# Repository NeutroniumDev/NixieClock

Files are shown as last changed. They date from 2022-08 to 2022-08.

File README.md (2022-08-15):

# NixieClock
  NOTE: this is not a completed project. The code is incomplete, and therefor the hardware has not been fully tested. DON'T BUILD THIS YET, OR ASSUME RISKS. 

  A clock consisting of 6 nixie tubes, controlled by 3 high voltage shift registers. It differs from most other nixie clocks in that every segment of every nixie tube can be turned on, as opposed to one number per tube. This enables more complex animations. The 3 high voltage shift registers also, theoretically (not implemented) support controlling more than 6 nixie tubes because of leftover pins. The clock uses an ESP32-C3 to enable synchronizing the time with NTP, and it also acts as the microcontroller. Finally, the clock technically has an RTC chip, although in retrospect it's sorta unnecessary (and not implemented in code lmao).

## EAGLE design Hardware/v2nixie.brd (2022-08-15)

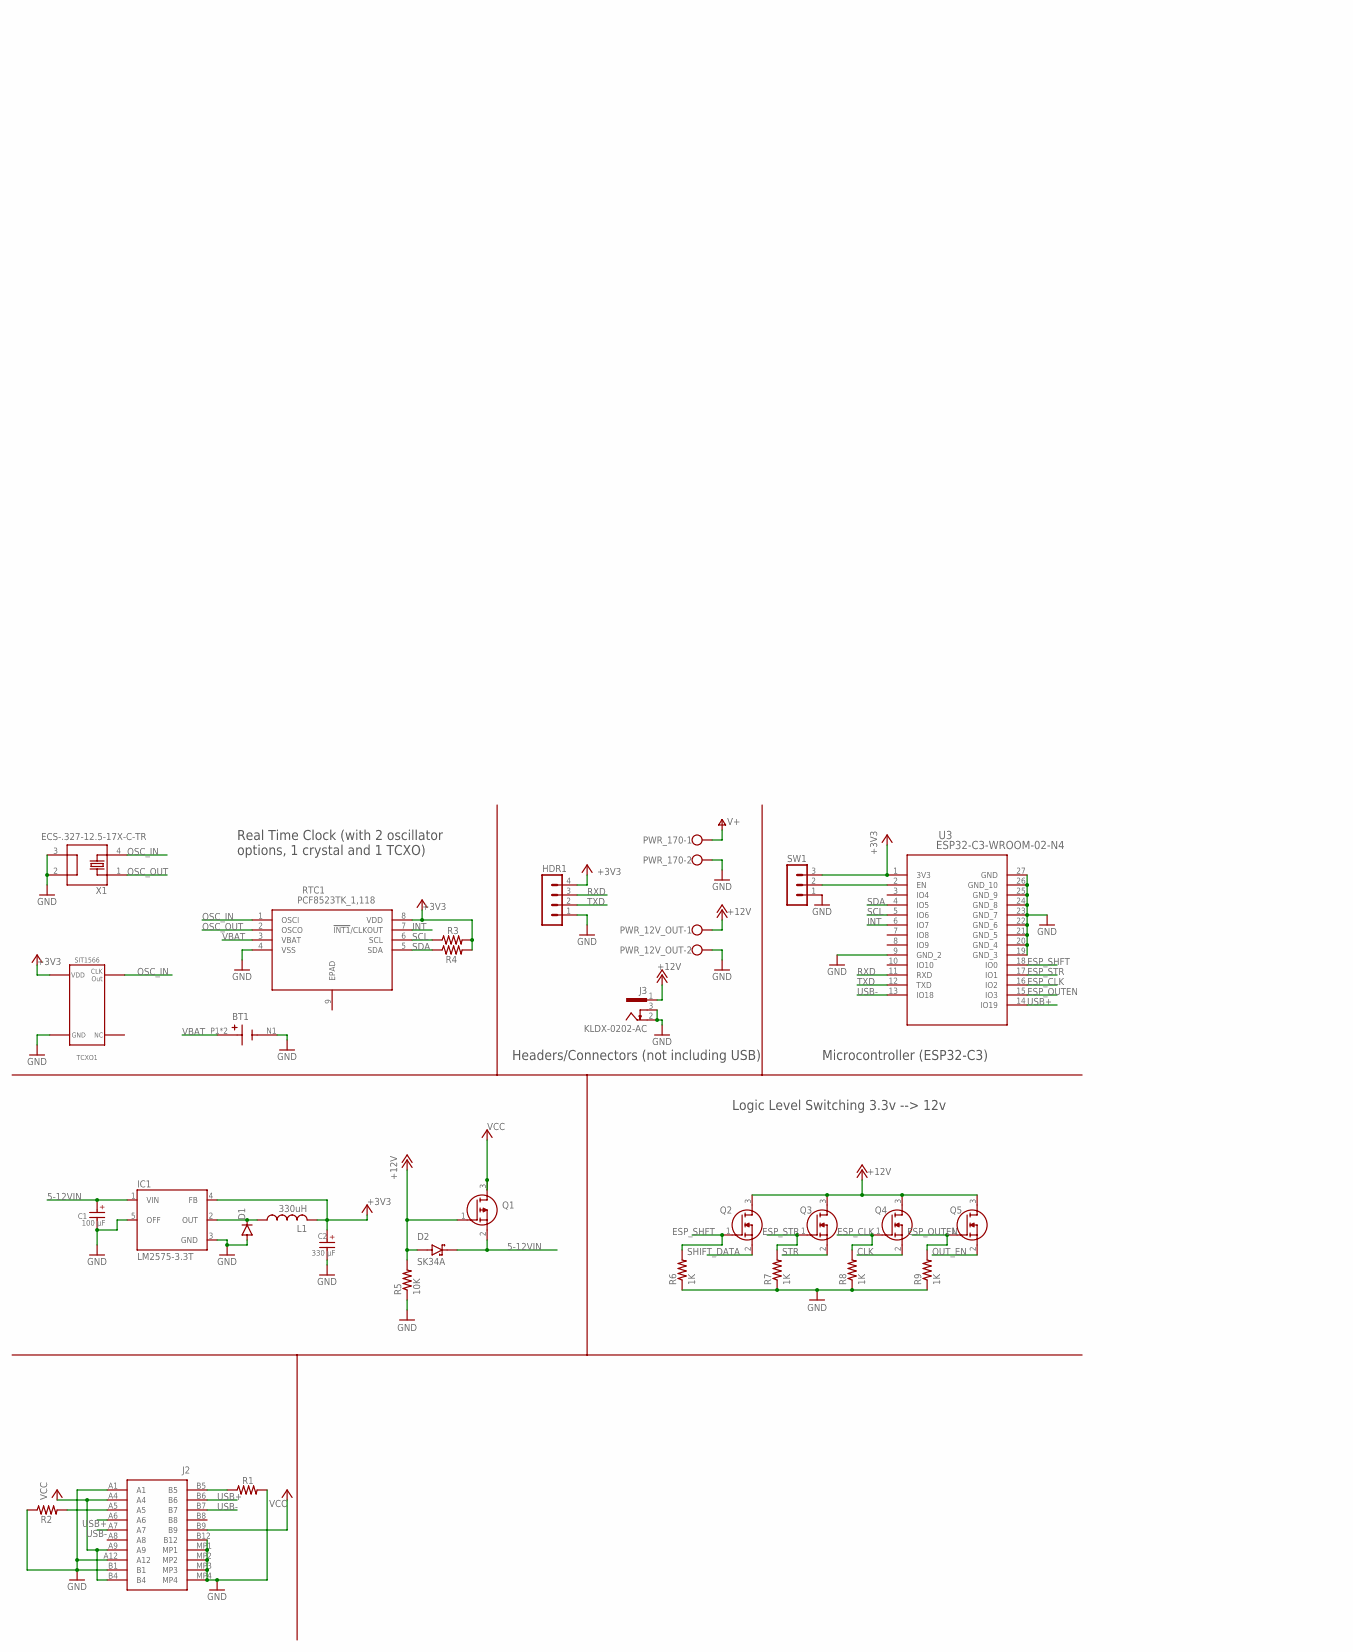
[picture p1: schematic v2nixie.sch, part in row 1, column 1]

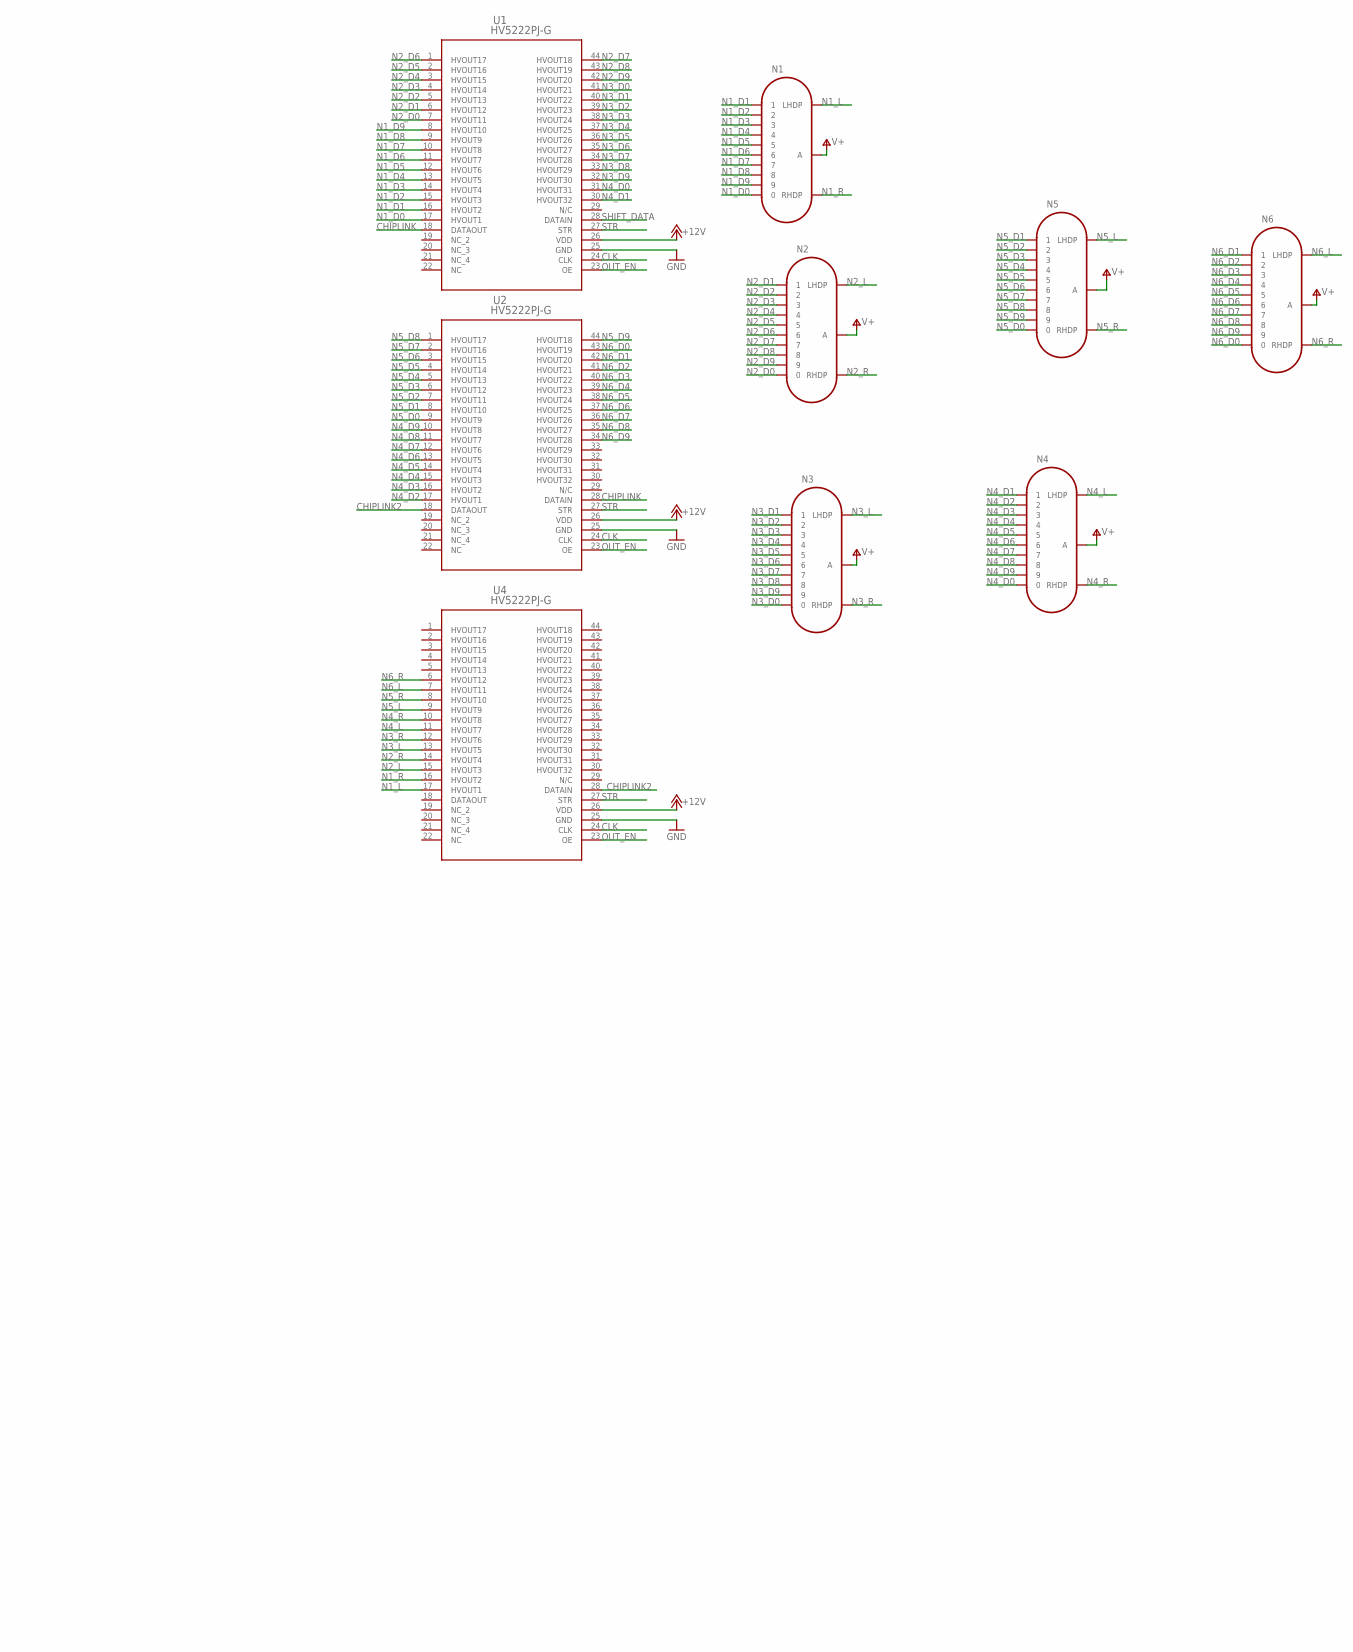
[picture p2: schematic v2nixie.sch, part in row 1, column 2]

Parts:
BT1: BAT-HLD-001-TR; BAT_BAT-HLD-001-TR
C1: 100 µF; WCAP-PTG5_8X11.5(DXL)
C2: 330 µF; WCAP-PTG5_8X8(DXL)
D1: DIODE-DO201-15; DO201-15
D2: SK34A; DIOM4325X250N
HDR1: MA04-1
IC1: LM2575-3.3T; TO220-5
J2: USB4110-GF-A; USB4110GFA
J3: KLDX-0202-AC; KYCON_KLDX-0202-AC
L1: 330uH; 6000-XXXX-RC
N1, N2, N3, N4, N5, N6: IN-14
PWR_12V_OUT, PWR_170: W237-102
Q1: SSM3J117TU,LF_T; SSM3J117TULFT
Q2, Q3, Q4, Q5: RU1J002YNTCL; SOTFL65P210X105-3N
R1, R2: 5.1K; R0805
R3, R4: 10K; R0805
R5: 10K; M0805
R6, R7, R8, R9: 1K; M0805
RTC1: PCF8523TK_1,118; SON80P400X400X100-9N
SW1: MA03-1
TCXO1: SIT1566
U1, U2, U4: HV5222PJ-G; PLCC44_MC_MCH
U3: ESP32-C3-WROOM-02-N4; IC18_ESP32-C3-WROOM-02-N4_EXP
X1: ECS-.327-12.5-17X-C-TR; XTAL_ECS-.327-12.5-17X-C-TR

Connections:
5-12VIN: C1.1 (+), D2.C (K), IC1.1 (VIN), Q1.2 (S)
+3V3: C2.1 (+), HDR1.4, IC1.4 (FB), L1.2, R3.2, R4.2, RTC1.8 (VDD), SW1.3, TCXO1.VDD, U3.1 (3V3)
+12V: D2.A, J3.1, PWR_12V_OUT.1, Q1.1 (G), Q2.3 (D), Q3.3 (D), Q4.3 (D), Q5.3 (D), R5.2, U1.26 (VDD), U2.26 (VDD), U4.26 (VDD)
CHIPLINK: U1.18 (DATAOUT), U2.28 (DATAIN)
CHIPLINK2: U2.18 (DATAOUT), U4.28 (DATAIN)
CLK: Q4.2 (S), U1.24 (CLK), U2.24 (CLK), U4.24 (CLK)
ESP_CLK: Q4.1 (G), R8.2, U3.16 (IO2)
ESP_OUTEN: Q5.1 (G), R9.2, U3.15 (IO3)
ESP_SHFT: Q2.1 (G), R6.2, U3.18 (IO0)
ESP_STR: Q3.1 (G), R7.2, U3.17 (IO1)
GND: BT1.N1 (-), C1.2 (-), C2.2 (-), D1.A, HDR1.1, IC1.3 (GND), IC1.5 (OFF), J2.A1, J2.A12, J2.B1, J2.B12, J2.MP1, J2.MP2, J2.MP3, J2.MP4, J3.2, J3.3, PWR_12V_OUT.2, PWR_170.2, R1.2, R2.1, R5.1, R6.1, R7.1, R8.1, R9.1, RTC1.4 (VSS), SW1.1, TCXO1.GND, U1.25 (GND), U2.25 (GND), U3.9 (GND_2), U3.19 (GND_3), U3.20 (GND_4), U3.21 (GND_5), U3.22 (GND_6), U3.23 (GND_7), U3.24 (GND_8), U3.25 (GND_9), U3.26 (GND_10), U3.27 (GND), U4.25 (GND), X1.2, X1.3
INT: RTC1.7 (!INT1!/CLKOUT), U3.6 (IO7)
N1_D0: N1.0, U1.17 (HVOUT1)
N1_D1: N1.1, U1.16 (HVOUT2)
N1_D2: N1.2, U1.15 (HVOUT3)
N1_D3: N1.3, U1.14 (HVOUT4)
N1_D4: N1.4, U1.13 (HVOUT5)
N1_D5: N1.5, U1.12 (HVOUT6)
N1_D6: N1.6, U1.11 (HVOUT7)
N1_D7: N1.7, U1.10 (HVOUT8)
N1_D8: N1.8, U1.9 (HVOUT9)
N1_D9: N1.9, U1.8 (HVOUT10)
N1_L: N1.LHDP, U4.17 (HVOUT1)
N1_R: N1.RHDP, U4.16 (HVOUT2)
N2_D0: N2.0, U1.7 (HVOUT11)
N2_D1: N2.1, U1.6 (HVOUT12)
N2_D2: N2.2, U1.5 (HVOUT13)
N2_D3: N2.3, U1.4 (HVOUT14)
N2_D4: N2.4, U1.3 (HVOUT15)
N2_D5: N2.5, U1.2 (HVOUT16)
N2_D6: N2.6, U1.1 (HVOUT17)
N2_D7: N2.7, U1.44 (HVOUT18)
N2_D8: N2.8, U1.43 (HVOUT19)
N2_D9: N2.9, U1.42 (HVOUT20)
N2_L: N2.LHDP, U4.15 (HVOUT3)
N2_R: N2.RHDP, U4.14 (HVOUT4)
N3_D0: N3.0, U1.41 (HVOUT21)
N3_D1: N3.1, U1.40 (HVOUT22)
N3_D2: N3.2, U1.39 (HVOUT23)
N3_D3: N3.3, U1.38 (HVOUT24)
N3_D4: N3.4, U1.37 (HVOUT25)
N3_D5: N3.5, U1.36 (HVOUT26)
N3_D6: N3.6, U1.35 (HVOUT27)
N3_D7: N3.7, U1.34 (HVOUT28)
N3_D8: N3.8, U1.33 (HVOUT29)
N3_D9: N3.9, U1.32 (HVOUT30)
N3_L: N3.LHDP, U4.13 (HVOUT5)
N3_R: N3.RHDP, U4.12 (HVOUT6)
N4_D0: N4.0, U1.31 (HVOUT31)
N4_D1: N4.1, U1.30 (HVOUT32)
N4_D2: N4.2, U2.17 (HVOUT1)
N4_D3: N4.3, U2.16 (HVOUT2)
N4_D4: N4.4, U2.15 (HVOUT3)
N4_D5: N4.5, U2.14 (HVOUT4)
N4_D6: N4.6, U2.13 (HVOUT5)
N4_D7: N4.7, U2.12 (HVOUT6)
N4_D8: N4.8, U2.11 (HVOUT7)
N4_D9: N4.9, U2.10 (HVOUT8)
N4_L: N4.LHDP, U4.11 (HVOUT7)
N4_R: N4.RHDP, U4.10 (HVOUT8)
N5_D0: N5.0, U2.9 (HVOUT9)
N5_D1: N5.1, U2.8 (HVOUT10)
N5_D2: N5.2, U2.7 (HVOUT11)
N5_D3: N5.3, U2.6 (HVOUT12)
N5_D4: N5.4, U2.5 (HVOUT13)
N5_D5: N5.5, U2.4 (HVOUT14)
N5_D6: N5.6, U2.3 (HVOUT15)
N5_D7: N5.7, U2.2 (HVOUT16)
N5_D8: N5.8, U2.1 (HVOUT17)
N5_D9: N5.9, U2.44 (HVOUT18)
N5_L: N5.LHDP, U4.9 (HVOUT9)
N5_R: N5.RHDP, U4.8 (HVOUT10)
N6_D0: N6.0, U2.43 (HVOUT19)
N6_D1: N6.1, U2.42 (HVOUT20)
N6_D2: N6.2, U2.41 (HVOUT21)
N6_D3: N6.3, U2.40 (HVOUT22)
N6_D4: N6.4, U2.39 (HVOUT23)
N6_D5: N6.5, U2.38 (HVOUT24)
N6_D6: N6.6, U2.37 (HVOUT25)
N6_D7: N6.7, U2.36 (HVOUT26)
N6_D8: N6.8, U2.35 (HVOUT27)
N6_D9: N6.9, U2.34 (HVOUT28)
N6_L: N6.LHDP, U4.7 (HVOUT11)
N6_R: N6.RHDP, U4.6 (HVOUT12)
unnamed: J2.A5, R2.2
unnamed: SW1.2, U3.2 (EN)
unnamed: J2.B5, R1.1
unnamed: D1.C, IC1.2 (OUT), L1.1
OSC_IN: RTC1.1 (OSCI), TCXO1.CLK_OUT, X1.4
OSC_OUT: RTC1.2 (OSCO), X1.1
OUT_EN: Q5.2 (S), U1.23 (OE), U2.23 (OE), U4.23 (OE)
RXD: HDR1.3, U3.11 (RXD)
SCL: R3.1, RTC1.6 (SCL), U3.5 (IO6)
SDA: R4.1, RTC1.5 (SDA), U3.4 (IO5)
SHIFT_DATA: Q2.2 (S), U1.28 (DATAIN)
STR: Q3.2 (S), U1.27 (STR), U2.27 (STR), U4.27 (STR)
TXD: HDR1.2, U3.12 (TXD)
USB+: J2.A6, J2.B6, U3.14 (IO19)
USB-: J2.A7, J2.B7, U3.13 (IO18)
V+: N1.A, N2.A, N3.A, N4.A, N5.A, N6.A, PWR_170.1
VBAT: BT1.P1 (+), BT1.P2 (+), RTC1.3 (VBAT)
VCC: J2.A4, J2.A9, J2.B4, J2.B9, Q1.3 (D)

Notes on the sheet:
Real Time Clock (with 2 oscillator options, 1 crystal and 1 TCXO)
Headers/Connectors (not including USB)
Microcontroller (ESP32-C3)
Logic Level Switching 3.3v --> 12v

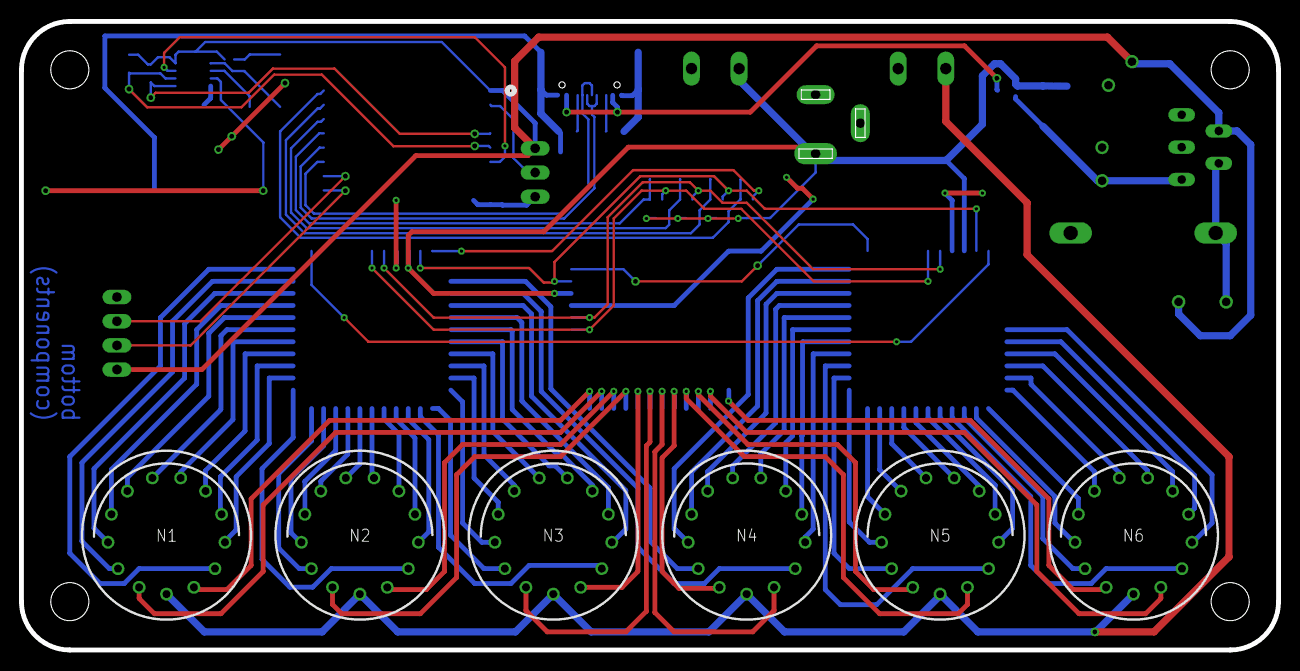
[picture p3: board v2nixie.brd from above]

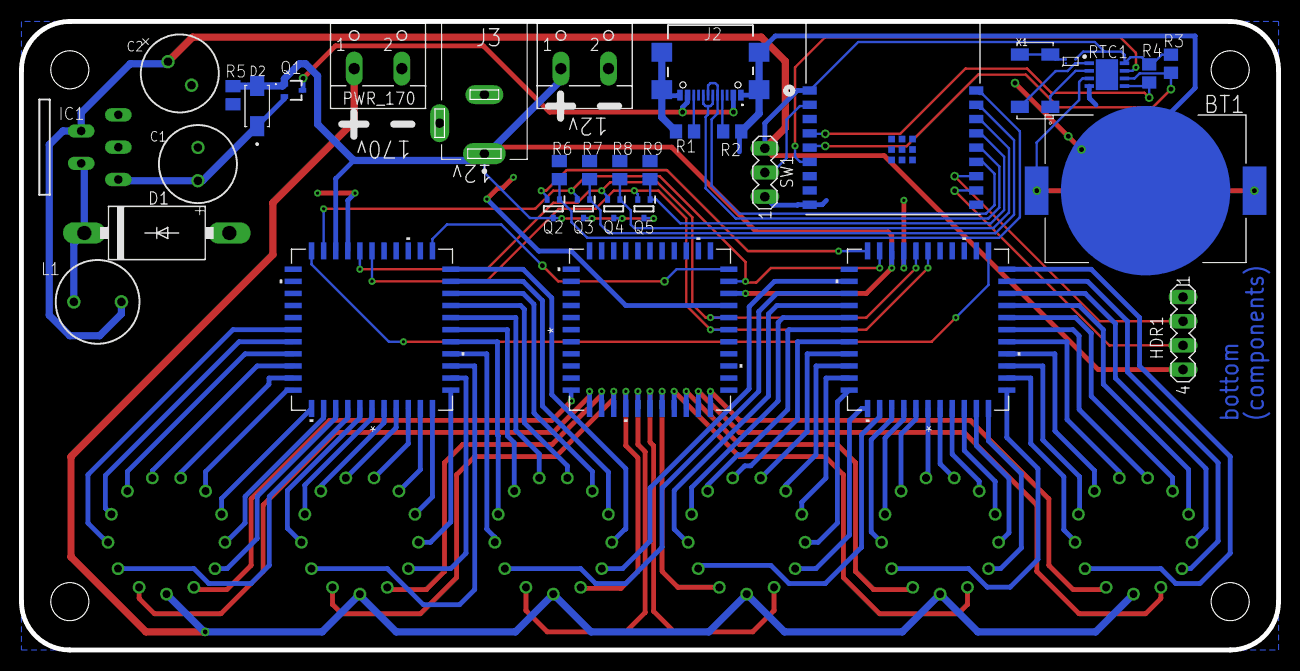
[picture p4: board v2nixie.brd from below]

Board: 2 copper layers, 132.1 x 66.0 mm, 40 parts (34 on the bottom side), 102 nets.

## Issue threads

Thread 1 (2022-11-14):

Nixie tubes need resistors for safe & continued operation at nominal voltage

NeutroniumDev, 2022-11-14:
Forgot to add this, oops!
Will likely need to redesign board (which I was gonna do anyways), and add a resistor on each cathode (rather than 1 per anode, so 1 per tube) to allow for multiple digits to be switched on at the same time. Thats gonna be a lot of frickin resistors.

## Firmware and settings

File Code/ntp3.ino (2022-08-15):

//this is mostly example code so don't expect it to be very optimized. 
//also, i'm shit at coding so... yeah. 
#include <WiFi.h>
#include "WiFiUdp.h" //no idea if this is required lol
#include "NTP.h"


const char *ssid     = "WIFI_NAME";
const char *password = "WIFI_PASSWORD";

WiFiUDP wifiUdp;
NTP ntp(wifiUdp);

int y = 0;
int mo = 0;
int d = 0;
int h = 0;
int m = 0;
int s = 0;

void setup() {
  Serial.begin(9600);
  WiFi.begin(ssid, password);

  while (WiFi.status() != WL_CONNECTED) {
    Serial.println("Connecting ...");
    delay(500);
    }

  Serial.println("Connected");  
  ntp.isDST(false);
  ntp.timeZone(-7, 0);
  ntp.begin();
  Serial.println("start NTP");
  updateNTP();
  
  }

void loop() {
  updateNTP();
  
  printTime();
  } 

void updateNTP() {
  ntp.update();
  y = ntp.year();
  mo = ntp.month();
  d = ntp.day();
  h = ntp.hours();  
  m = ntp.minutes();
  s = ntp.seconds();
  Serial.println("Synced time through NTP");
  }

void printTime() {
  Serial.print(d);
  Serial.print("/");
  Serial.print(mo);
  Serial.print("/");
  Serial.println(y);
  Serial.print("The exact time is ");
  Serial.print(h);
  Serial.print(":");
  Serial.print(m);
  Serial.print(":");
  Serial.println(s);
  }

void writeNixie(int tubeNumber, int digit, bool state) { //writes a number to a selected nixie
  int boolIndex = (10 * (tubeNumber - 1) + digit);       //note: writing to the L/R periods has not been implemented yet. 
  bool dispBits[boolIndex] = {state};
  }


void clearNixies() { //turns all the nixies off
  for (int i = 0; i < 96; i++) {
        bool dispBits[i] = {LOW};
    }
  }

void writeShiftR(int clkPin, int dataPin) { //writes the data to shift registers
  for (int i = 95; i >= 0; i--) {
      digitalWrite(clkPin, HIGH);
      digitalWrite(dataPin, dispBits[i]);
      digitalWrite(clkPin, LOW);
    }
  }

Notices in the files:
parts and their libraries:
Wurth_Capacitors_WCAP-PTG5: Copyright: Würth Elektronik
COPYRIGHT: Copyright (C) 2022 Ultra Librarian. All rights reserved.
